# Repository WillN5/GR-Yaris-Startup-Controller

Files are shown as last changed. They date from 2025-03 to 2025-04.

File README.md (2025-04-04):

# GR Yaris Startup Controller V1.0

Version 2.0 now available

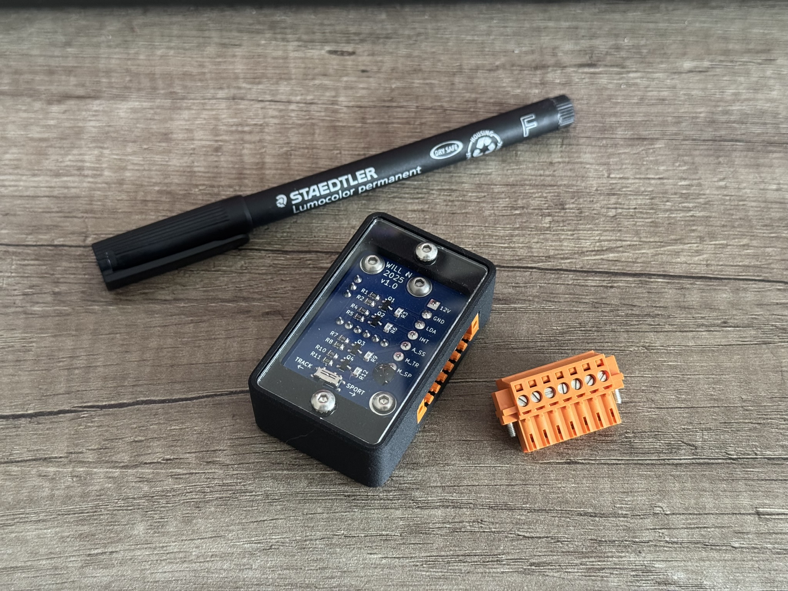
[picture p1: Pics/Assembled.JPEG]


This device will automatically press any (or all) of the annoying buttons in a GR Yaris when you first start your car:
* Lane Departure Alert (turn off)
* iMT (turn on)
* Auto Stop/Start (turn off)
* Select Sport/Track mode

In this repository you will find:
* [Overview & Installation Guide](https://github.com/WillN5/GR-Yaris-Startup-Controller/tree/main/Docs)
* [Car wiring information](https://github.com/WillN5/GR-Yaris-Startup-Controller/tree/main/Docs)
* [PCB schematic](https://github.com/WillN5/GR-Yaris-Startup-Controller/tree/main/PCB)
* [Code](https://github.com/WillN5/GR-Yaris-Startup-Controller/tree/main/Code/Startup_Controller_Code_V1)
* [3D files for the case](https://github.com/WillN5/GR-Yaris-Startup-Controller/tree/main/Housing)
* [Pictures](https://github.com/WillN5/GR-Yaris-Startup-Controller/tree/main/Pics)

Credit for idea goes to MagnusT and his original post here:<br/>
https://www.gr-yaris.co.uk/threads/automatic-shut-off-of-all-lane-assist-everytime-you-start-the-car.2947/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<br/>
This project is a development of that idea to include the additional button presses, wrapped up in a (hopefully) neat package.

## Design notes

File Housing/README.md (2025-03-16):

# Housing Assembly
The case requires the following parts:

* Main Housing (3D print)
* Spacer (3D print)
* Cover (3D print / laser cut 2mm thk)

* 3x M3x6 button head screws
* 2x M3x12 button head screws
* 5x M3 heat set inserts

</br>
</br>

Exploded Assembly View:</br>
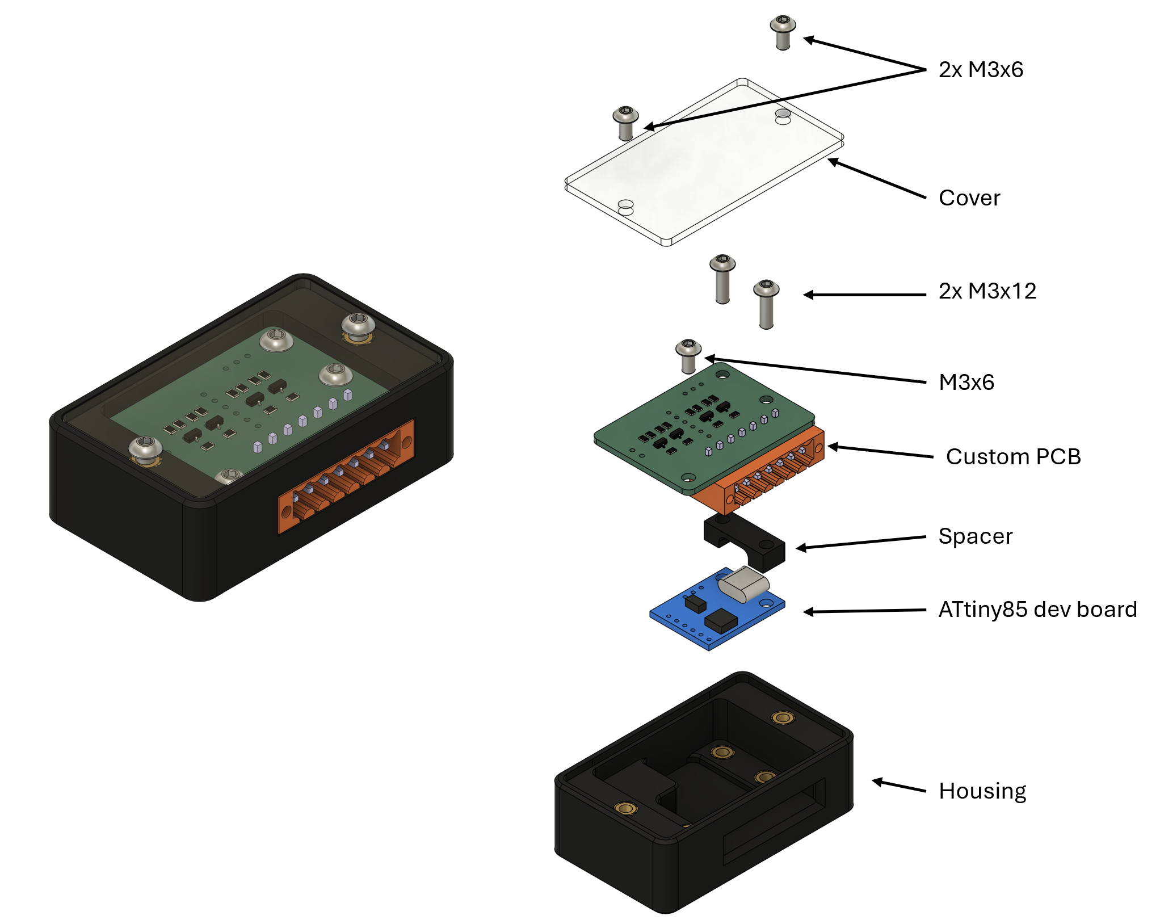
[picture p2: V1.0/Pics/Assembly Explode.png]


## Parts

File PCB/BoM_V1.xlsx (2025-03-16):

Reference | Qty | Value | RS Part No. | Footprint | Datasheet | Description
J1 | 1 | 1607090000 | 762-6321 | Weidmuller7WayTerminal1607090000:Weidmuller7WayTerminal1607090000 | http://catalog.weidmueller.com/createDatasheetForMobile.do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 | PCB plug-in connector, male header, Flange, THT solder connection, 3.50 mm, Number of poles: 7, 90, Solder pin length: 3.2 mm, tinned, orange, Box
Q1,Q2,Q3,Q4 | 4 | MMBT2222A | 725-8607P | Package_TO_SOT_SMD:SOT-23 | https://assets.nexperia.com/documents/data-sheet/MMBT2222A.pdf | 600mA Ic, 40V Vce, NPN Transistor, SOT-23
R1,R4,R7,R10 | 4 | 5k1 | - | Resistor_SMD:R_0805_2012Metric | ~ | Resistor
R2,R5,R8,R11 | 4 | 10k | - | Resistor_SMD:R_0805_2012Metric | ~ | Resistor
R3,R6,R9,R12 | 4 | 330R | - | Resistor_SMD:R_0805_2012Metric | ~ | Resistor
S1 | 1 | Wuerth 450404015514 | 254-1818 | Wuerth SPDT Slide Switch 50404015514:450404015514 | https://katalog.we-online.de/em/datasheet/450404015514.pdf | Slide Switch SPDT Surface Mount
U1 | 1 | ATtiny85 Breakout Board USB-C | - | ATtiny85-DevBoard-USB-C:ATtiny85-DevBoard-USB-C | https://www.aliexpress.com/item/1005007681466941.html | DigiSpark ATtiny85 breakout board
 |  | J1 mating plug: | 762-6062 | Weidmuller, 3.5mm Pitch, BL, 7 Way, Pluggable Terminal Block, Plug, Cable Mount, Screw Termination, 1606690000

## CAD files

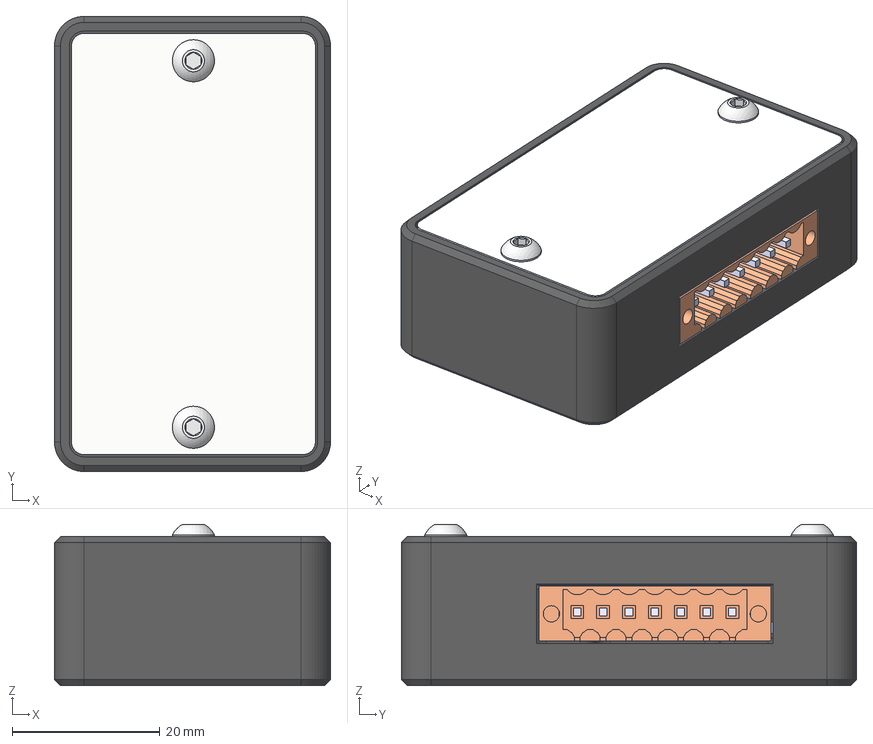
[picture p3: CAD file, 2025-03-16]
Housing/Complete Assembly.step
37.4 x 61.6 x 21.8 mm
SOT-23 x 4
R_0805_2012Metric x 12
ATtiny85-DevBoard-USB-C
Weidmuller7WayTerminal1607090000.3dshapes
GR Yaris_PCB
Housing
Cover
94180A331_NO THREADS_Tapered Heat-Set Inserts for Plastic x 5
92095A182_NO THREADS_Button Head Hex Drive Screw x 2
92095A179_NO THREADS_Button Head Hex Drive Screw x 3
Spacer
91294A128_NO THREADS_Black-Oxide Alloy Steel Hex Drive Flat Head Scre w

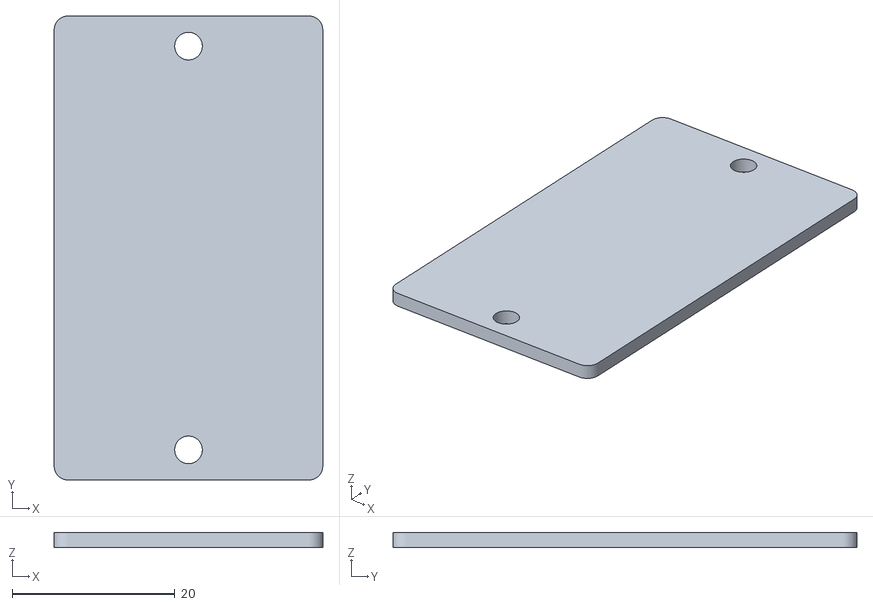
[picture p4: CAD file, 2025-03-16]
Housing/3D Print/Cover.stl
33.0 x 57.0 x 1.90

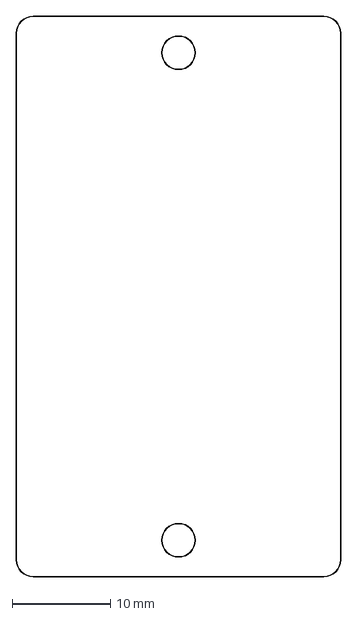
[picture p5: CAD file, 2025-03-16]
Housing/Laser cut (optional)/Cover DXF.dxf
33.0 x 57.0 mm

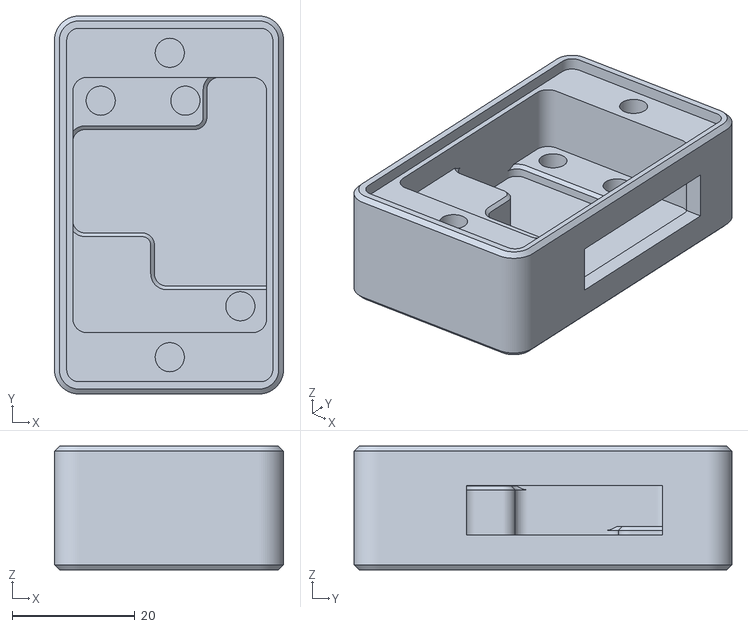
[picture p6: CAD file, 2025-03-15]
Housing/3D Print/Housing.stl
37.3 x 61.6 x 20.1

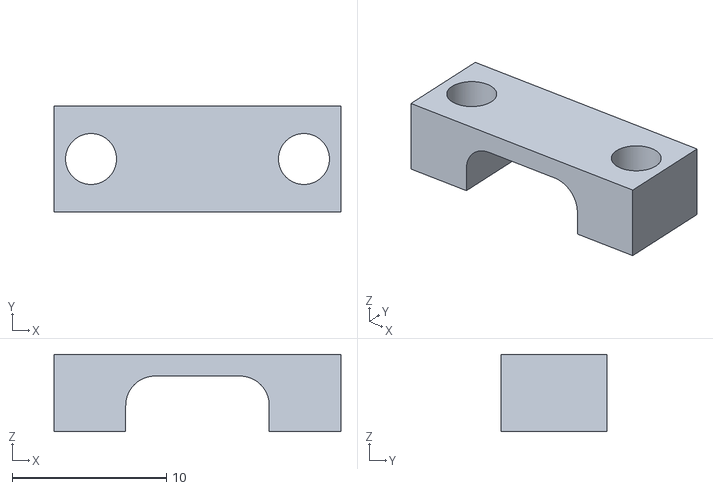
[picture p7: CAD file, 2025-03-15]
Housing/3D Print/Spacer.stl
18.6 x 6.90 x 5.01

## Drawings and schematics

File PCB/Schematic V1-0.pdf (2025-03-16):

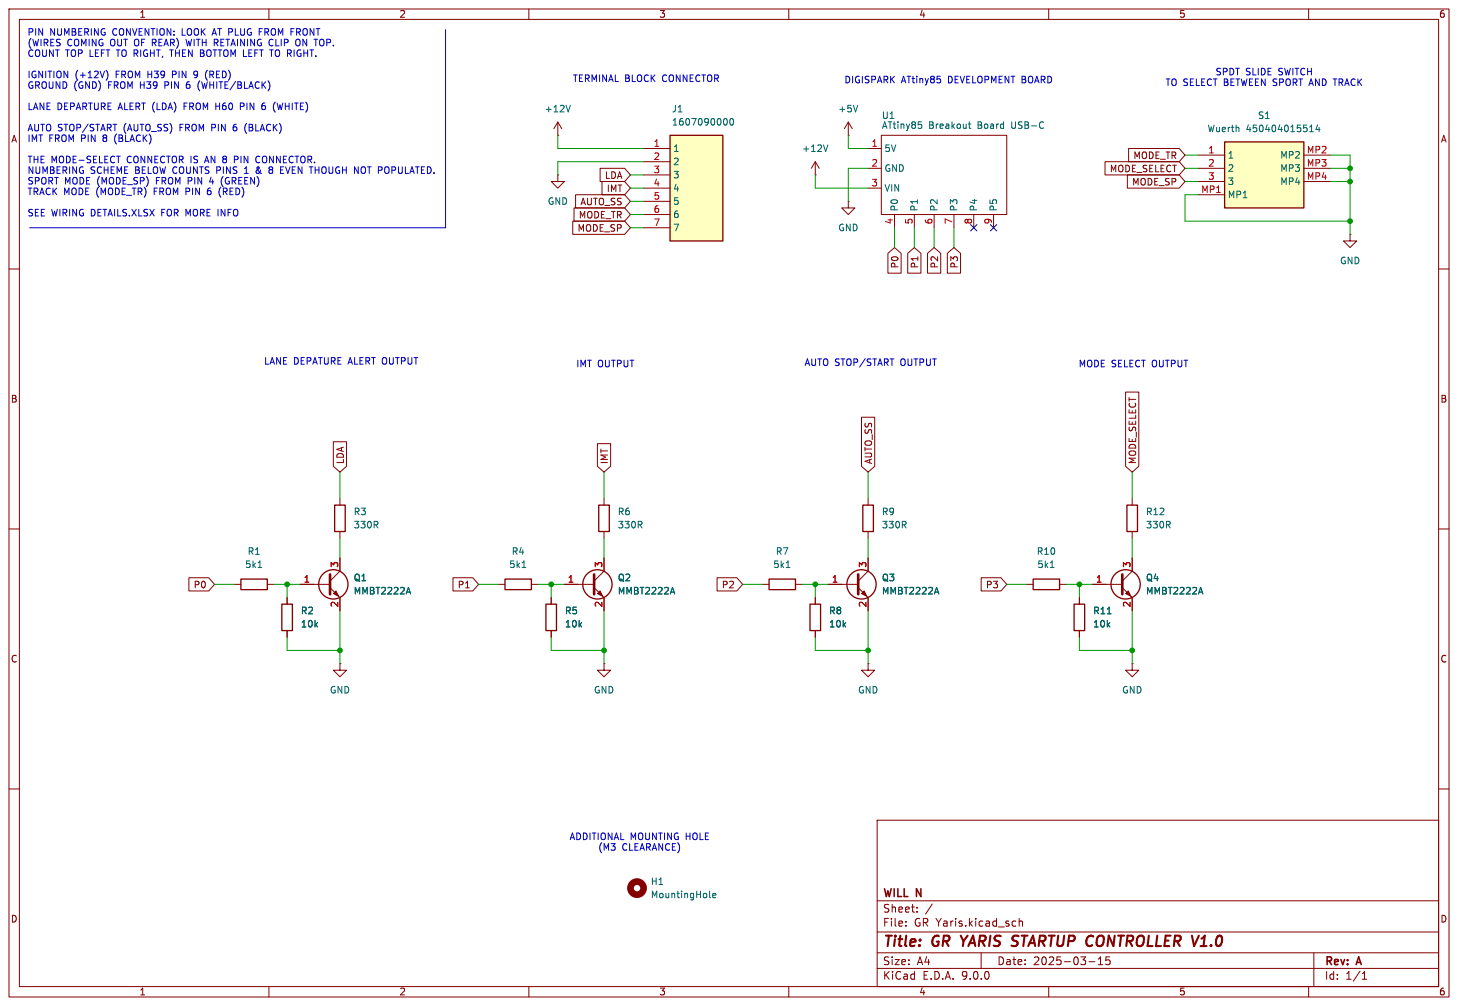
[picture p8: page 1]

(WIRES COMING OUT OF REAR) WITH RETAINING CLIP ON TOP. COUNT TOP LEFT TO RIGHT, THEN BOTTOM LEFT TO RIGHT.

TO SELECT BETWEEN SPORT AND TRACK

Id: 1/1 Title: GR YARIS STARTUP CONTROLLER V1.0

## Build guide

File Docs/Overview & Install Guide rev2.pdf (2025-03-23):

# GR Yaris Startup Controller V1.0

## Overview & Installation guide

WILLN on GR-Yaris.co.uk
will.norman@sky.com

I TAKE NO RESPONSIBILITY FOR ANY DAMAGE CAUSED DURING THE INSTALLATION OR OPERATION OF THE DEVICE. INSTALL AT YOUR OWN RISK

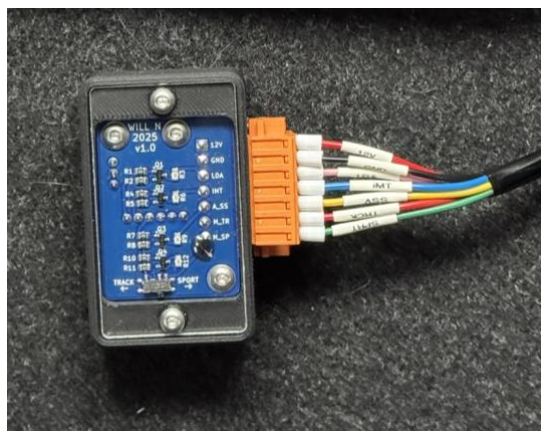
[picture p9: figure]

Rev | Description | Date updated
2 | Install guide updated | 23/03/25

# 2. Overview - Operation

Every time the car ignition powers on, the “GR Yaris Startup Controller” turns on and automatically:
- Switches off the lane departure alert
- Switches off auto stop/start
- Switches on iMT
- Selects the driving mode (sport/track)

It does this by simply mimicking button presses electronically. If you don’t want all the buttons pressed, wire only the ones you desire and leave the rest empty (i.e., wire in lane departure alert and leave the rest unconnected)

If you don’t feel comfortable splicing into the factory wiring (like me), you can buy short extension harnesses that plug inline, allowing you to splice in without cutting into the factory wires. See links on subsequent slides for where to purchase these extensions.

# 3. Overview - Design

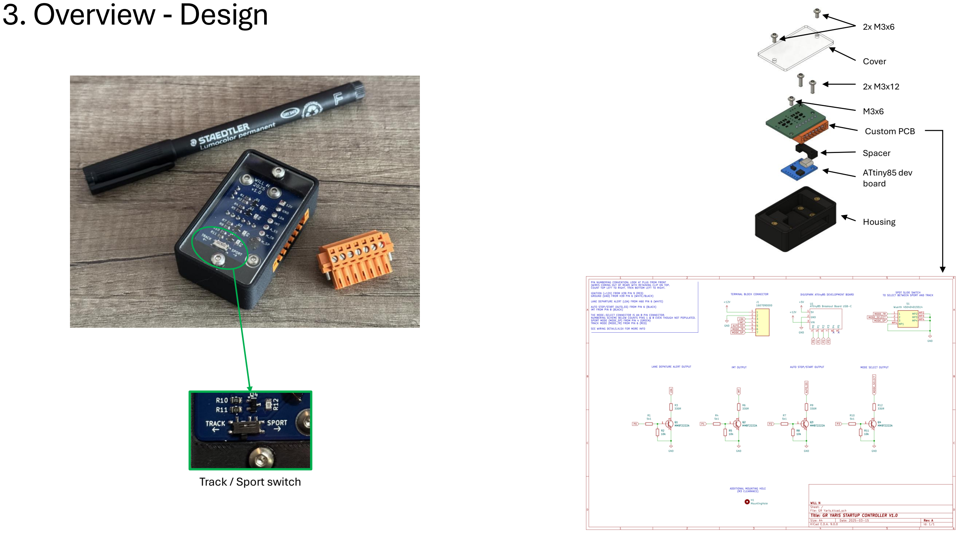
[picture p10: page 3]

Cover

ATtiny85 dev
board

Housing

Spacer

M3x6

2x M3x12

2x M3x6

Custom PCB

Track / Sport switch

# 4. Controller Wiring

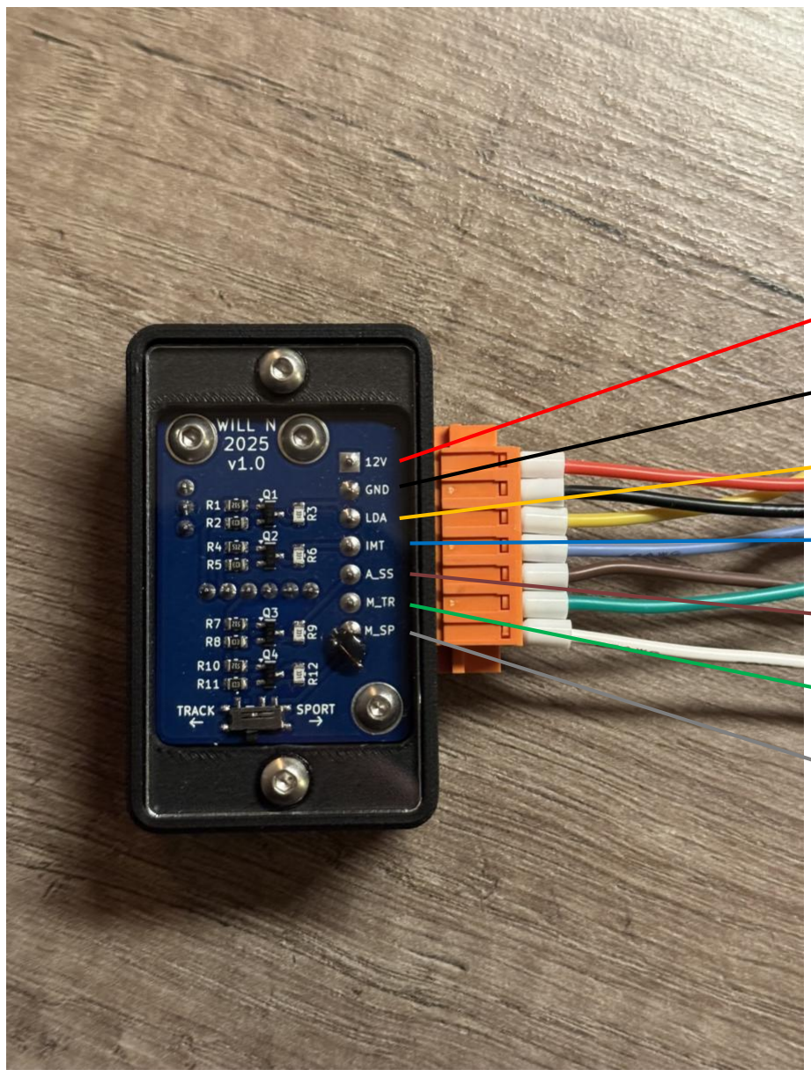
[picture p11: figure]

1. +12V (Ignition)^
2. GND^
3. LANE DEPARTURE ALERT*
4. iMT*
5. AUTO STOP / START*
6. TRACK MODE*
7. SPORT MODE*

See page 5

See page 8

See page 7

See page 6

^mandatory
*optional

# 5. Ignition Power + Ground

The wiring for +12V, GND is found under the steering wheel cowling. The cowling is removed by undoing 3x screws. (Rotate the steering wheel to reveal 2 hidden screws)

+12V (Ignition) and Ground are taken from the 10-pin connector (H39):

Pin number 9 (Red) = +12V (Ignition)
Pin number 6 (White & black stripe) = Ground

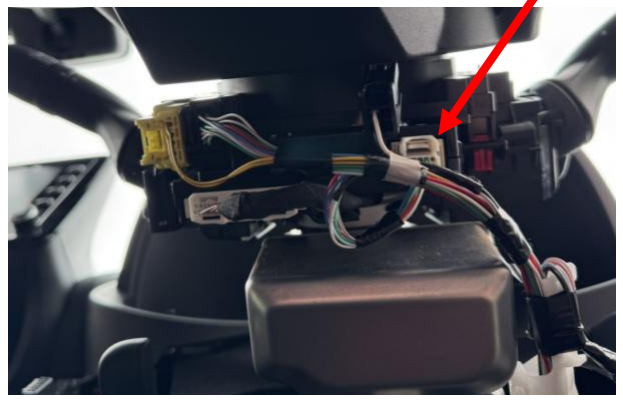
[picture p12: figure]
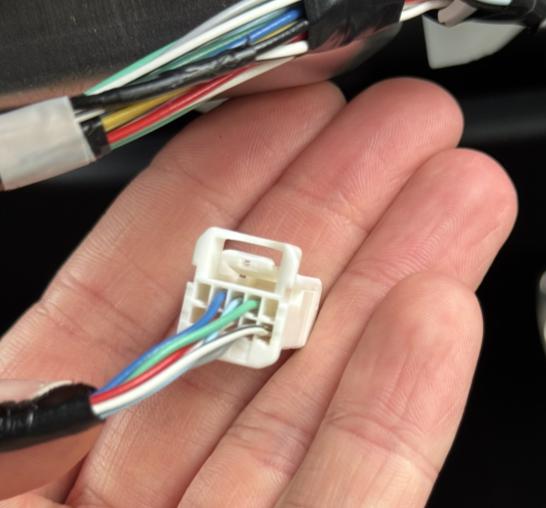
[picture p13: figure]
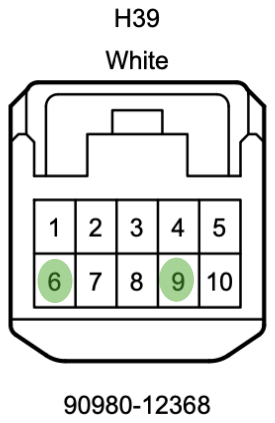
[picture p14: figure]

If you don’t want to splice into the factory wiring, short extension harnesses can be purchased here that you can modify:
10-pin extension harness (https://www.aliexpress.com/item/1005004458461883.html)
Another option that should work (https://www.aliexpress.com/item/1005005530620188.html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)

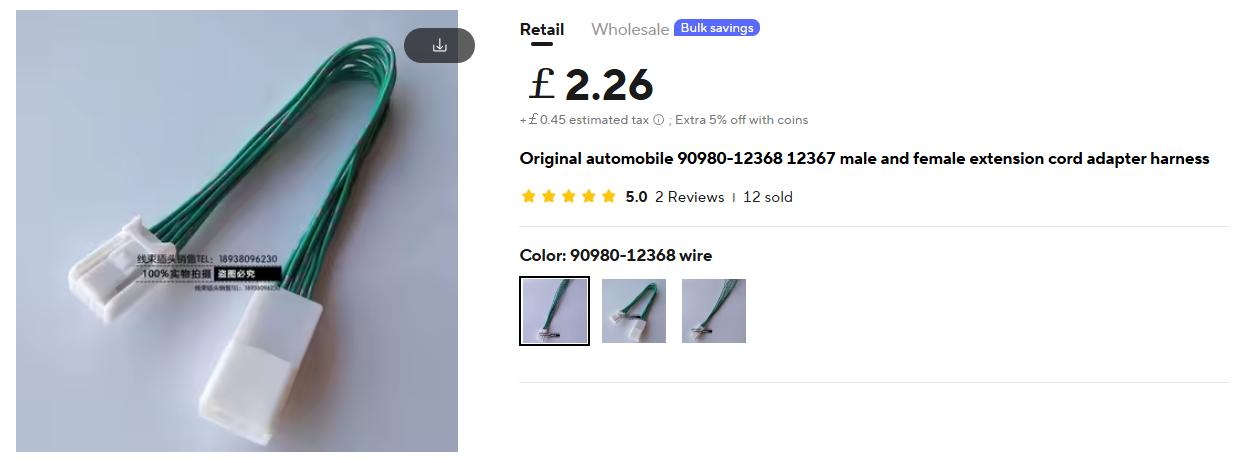
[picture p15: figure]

# 6. Lane Departure Alert

The wiring for LDA is also found under the steering wheel cowling

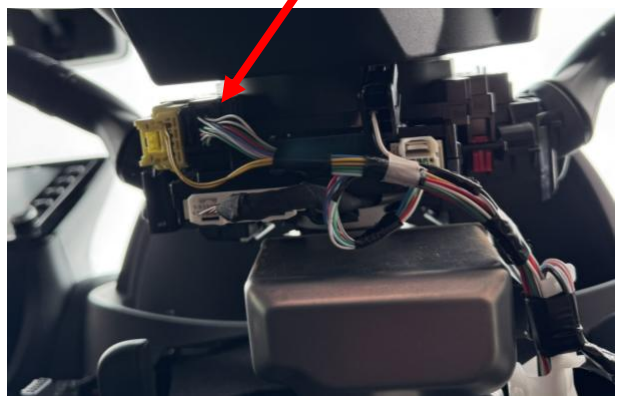
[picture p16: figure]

LDA is taken from the 14-pin connector (H60):

Pin number 6 (White) = Lane Departure Alert (LDA)

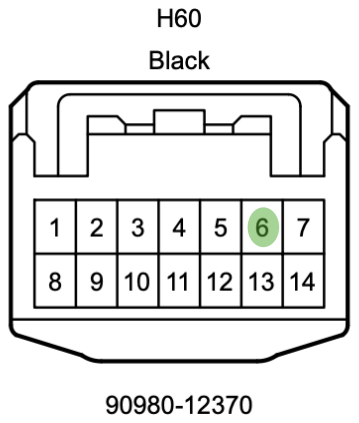
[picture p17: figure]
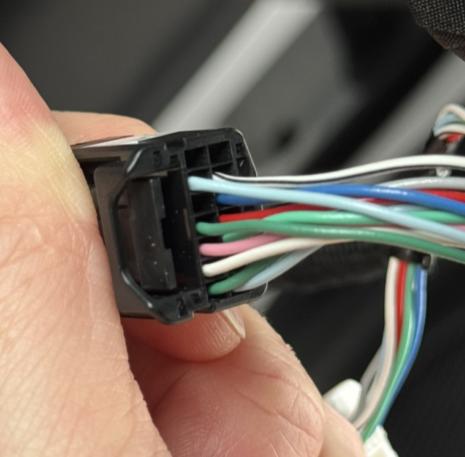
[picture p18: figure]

If you don’t want to splice into the factory wiring, short extension harnesses can be purchased here that you can modify:
14-pin extension harness (https://www.aliexpress.com/item/1005003780291406.html)

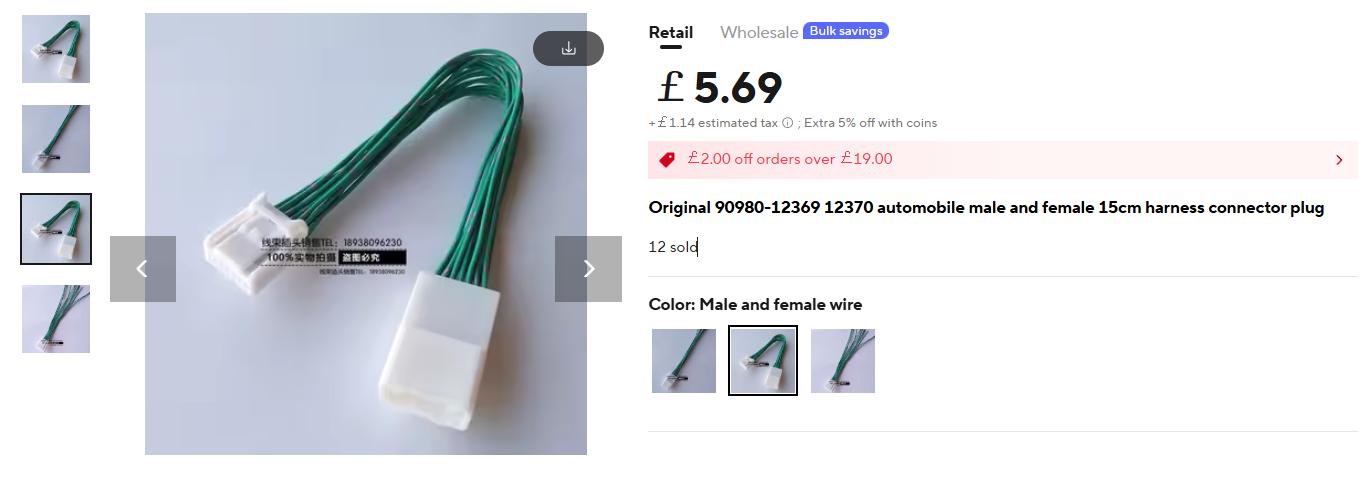
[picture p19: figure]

# 7. iMT & Auto Stop/Start

The wiring loom needed for iMT and Auto Stop/Start is found under the centre console
(plugged into the iMT/ESP/Auto stop start multi-button)

iMT and Auto Stop/Start are both found on the 8-pin connector that plugs into the button unit: Pin number 8 (Black) = iMT
Pin number 6 (Black) = Auto stop/start

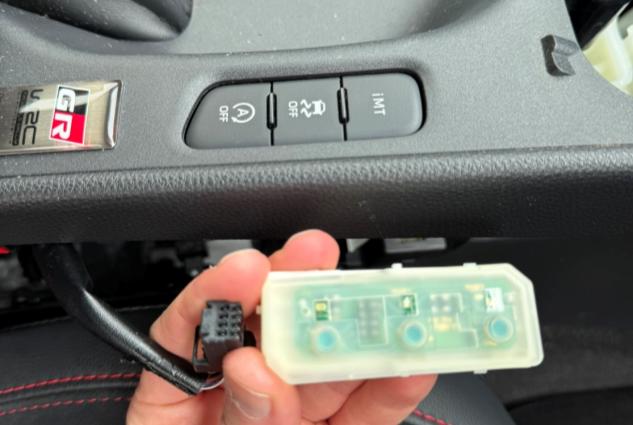
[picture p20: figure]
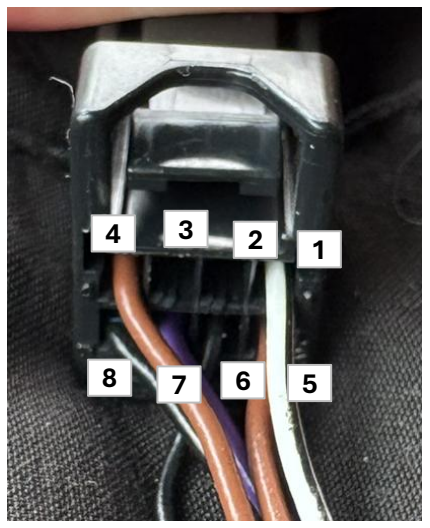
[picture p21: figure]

This 8-pin connector is:

Plug: Tokai Rika 4A1330-000 (Toyota 90980-12910) Socket: Tokai Rika 4B1160-000

A supplier is yet to be found…

# 8. Driving Mode – Sport / Track

The wiring loom needed for Sport/Track mode select is found under the centre console
(plugged into the drive mode rotary button)

Sport and Track mode are both found in the 8-pin connector that plugs into the drive mode rotary button. (Note pins 1 and 8 are empty in the plug but still counted here):

Pin number 4 (Green) = Sport
Pin number 6 (Red) = Track

You can wire both sport and track into the controller and use the slide switch on the PCB to choose between them. The slide switch must be in the appropriate position if you decide to wire only Sport or Track.

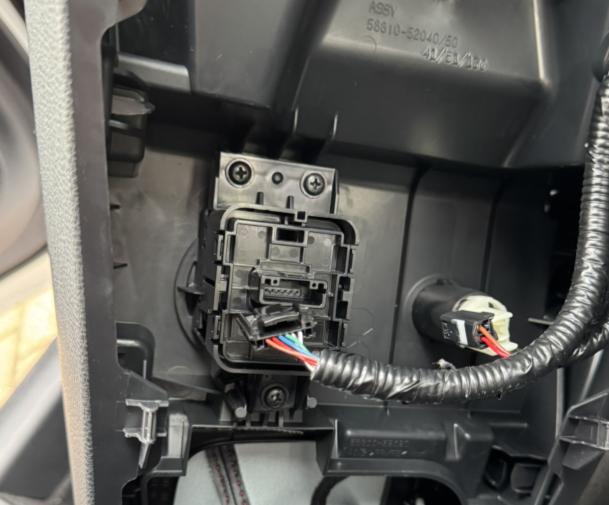
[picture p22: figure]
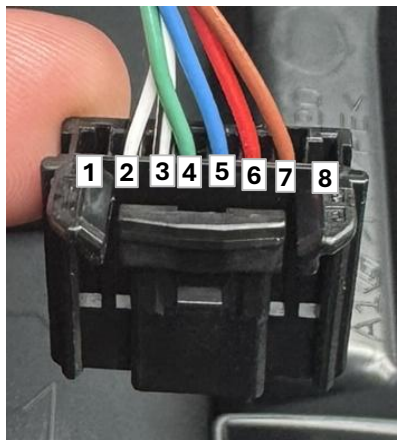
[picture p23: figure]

If you don’t want to splice into the factory wiring, a short extension harness can be made up using these connectors:
8-pin plug + socket + crimp pins (https://www.aliexpress.com/item/1005001297466790.html?mp=1)
(choose the “Upper slot female” version)

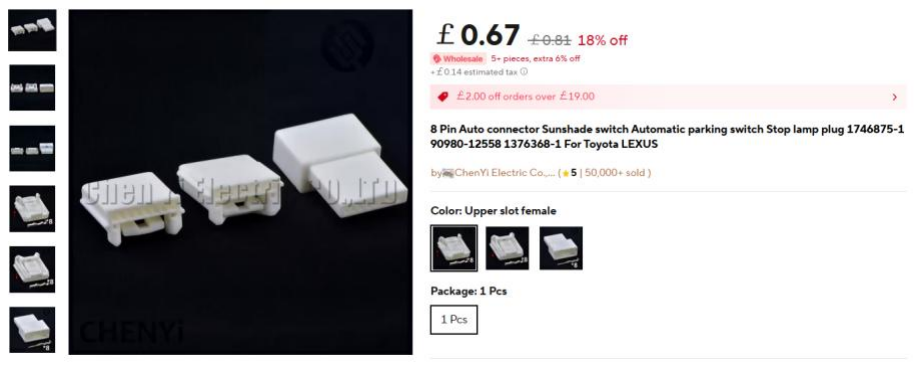
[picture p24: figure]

# 9. Helpful Links

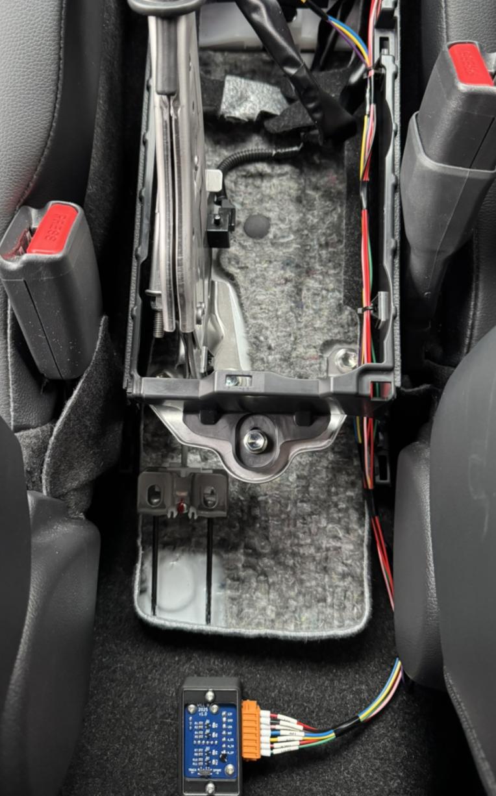
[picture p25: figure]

Project files and information on GitHub (https://github.com/WillN5/GR-Yaris-Startup-Controller/tree/main)
Link to forum post where idea initially discussed by MagnusT (https://www.gr-yaris.co.uk/threads/automatic-shut-off-of-all-lane-assist-everytime-you-start-the-car.2947/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) How to pull apart the centre console (https://www.youtube.com/watch?v=YhoG59Sv5QI)
22 AWG wire (https://www.ebay.co.uk/itm/301224679633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)
Ferrule crimp kit (https://www.amazon.co.uk/dp/B07GDGJ5K6?ref=ppx_yo2ov_dt_b_fed_asin_title)

1) Power & Ground Options
A. 10-pin extension harness (https://www.aliexpress.com/item/1005004458461883.html)
B. Another 10-pin option that should work (https://www.aliexpress.com/item/1005005530620188.html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)
2) Lane Departure Alert: 14-pin extension harness (https://www.aliexpress.com/item/1005003780291406.html)
3) Sport/Track Mode: 8-pin plug + socket + crimp pins (https://www.aliexpress.com/item/1005001297466790.html?mp=1) (upper slot female)
4) iMT/ESP/Auto Stop Start: 8-pin **Yet to be found**

# 10. Extension Harnesses

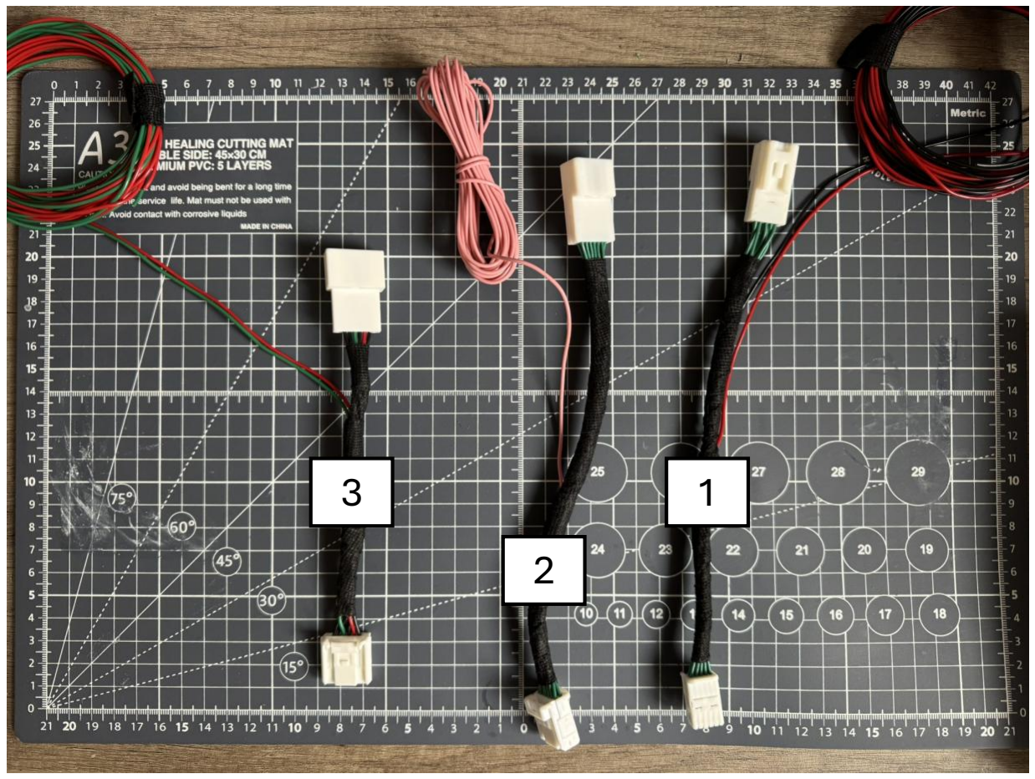
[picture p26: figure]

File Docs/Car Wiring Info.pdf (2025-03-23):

Control box pin
Socket: | 90980-12369
Plug: | 90980-12370
Plug pin | Colour | Function
1
2
3
4
5
6 | White | Lane departure alert (LDA) | LDA
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
Parts: H60 harness extension

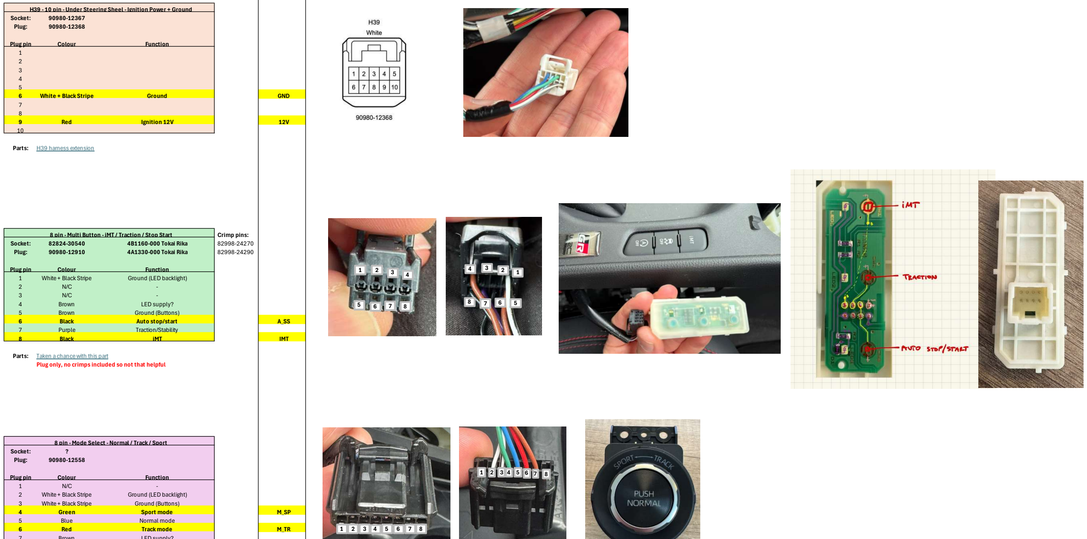
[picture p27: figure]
Socket:; Plug:; Plug pin; Colour; Function; White + Black Stripe; Ground; GND; Red; Ignition 12V; Parts: H39 harness extension; Crimp pins:; 4B1160-000 Tokai Rika; 4A1330-000 Tokai Rika; Ground (LED backlight); Brown; LED supply?; Ground (Buttons); Black; Auto stop/start; Purple; Traction/Stability; iMT; IMT; Parts: Taken a chance with this part; Green; Sport mode; Blue; Normal mode

Plug only, no crimps included so not that helpful

6 | Red | Track mode | M_TR
7 | Brown | LED supply?
8 | N/C | -

Parts: Mode select plug + socket + pins, waiting for parts for confirmation of compatibility
| Upper slot female version

### 8 pin - Multi Button - iMT / Traction / Stop Start

### 8 pin - Mode Select - Normal / Track / Sport

H60 - 14 pin - Under Steering Wheel - Lane Departure Alert

H39 - 10 pin - Under Steering Sheel - Ignition Power + Ground | 1 2 3 4 5 6 7 8

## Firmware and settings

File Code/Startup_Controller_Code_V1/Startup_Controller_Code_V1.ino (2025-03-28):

// Will Norman
// March 2025
// GR Yaris Startup Controller
// For use with PCB v1.0

// To program the ATtiny85 dev board, you must include the following:
// File / Preferences / Additional boards manager URLs:
// http://drazzy.com/package_drazzy.com_index.json
// Boards Manager --> Install "ATTinyCore" by Spence
// Tools / Board: ATTinyCore / ATtiny85 (Micronucleus / DigiSpark)

#include <avr/sleep.h>

// Define output pins
#define LDA 0
#define IMT 1
#define A_SS 2
#define MODE_SELECT 3

void setup() {

  // Setup pins as outputs
  pinMode(LDA,OUTPUT);
  pinMode(IMT,OUTPUT);
  pinMode(A_SS,OUTPUT);
  pinMode(MODE_SELECT,OUTPUT);
  
  // Ensure pins are driven low
  digitalWrite(LDA,LOW);
  digitalWrite(IMT,LOW);
  digitalWrite(A_SS,LOW);
  digitalWrite(MODE_SELECT,LOW);

  // wait 12 seconds - give time for screen to load to debug
  delay(12000);

  // Press buttons sequentially

  // Lane departue alert
  digitalWrite(LDA,HIGH); // press LDA
  delay(4000); // wait long time
  digitalWrite(LDA,LOW); // release LDA
  delay(1000); // wait short time

  // iMT
  digitalWrite(IMT,HIGH); // press iMT
  delay(700); // wait short time
  digitalWrite(IMT,LOW); // release iMT
  delay(1000); // wait short time

  // Auto stop/start
  digitalWrite(A_SS,HIGH); // press stop/start
  delay(700); // wait short time
  digitalWrite(A_SS,LOW); // release stop/start
  delay(1000); // wait short time

  // Sport / track mode
  digitalWrite(MODE_SELECT,HIGH); // press mode select
  delay(700); // wait short time
  digitalWrite(MODE_SELECT,LOW); // release mode select
  delay(1000); // wait short time

  // sleep device
  set_sleep_mode(SLEEP_MODE_PWR_DOWN);
  sleep_enable();
  sleep_mode(); 

}

void loop() {

}

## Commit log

2025-03-15 First commit
    First commit
    [Cover DXF.dxf, Cover.stl, GR Yaris Startup Controller.step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]
2025-03-15 Schematic + gerbers first upload
    Schematic + gerbers first upload
2025-03-16 Case files updated
    [Cover DXF.dxf, Cover.stl, Housing.stl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]
2025-03-16 Housing rearrange
    [Complete Assembly.step, Cover DXF.dxf, Cover.stl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]
2025-03-16 Housing update
2025-03-16 Schematic updated
2025-03-16 Update to ATtinyCore board platform
2025-03-16 BoM Upload
    [BoM_V1.xlsx]
2025-03-16 Update Car Wiring Info.xlsx
2025-03-16 Updated schematic
2025-03-17 Commented out PB2 (bad PCB)
2025-03-23 Wiring info updated with pics
2025-03-28 Updated to sequential button presses with generous timings
